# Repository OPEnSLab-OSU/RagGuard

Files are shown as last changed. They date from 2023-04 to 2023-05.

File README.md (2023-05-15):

# 🚽 RagGuard | [Wiki](https://github.com/OPEnSLab-OSU/RagGuard/wiki)
Project Lead: **Dylan Heisey**
Project Members: **Aiden Olsen**

Sewer pipes carry waste that contains fats, oils, grease (FOG), and other debris that can cause buildup and complications in the system. The RagGuard project aims to protect sensors in these pipes from FOG and debris buildup that can affect the integrity of readings. Using a motor, the RagGuard periodically shakes itself and the sensor to reduce the amount of debris affecting the sensor's performance.

More information about assembly, testing, and operation can be found at the [wiki](https://github.com/OPEnSLab-OSU/RagGuard/wiki).

# ⚙️ RagGuard Programming Instructions

## 🛠️ Arduino UNO Setup:
#### ↬ The Arduino UNO must be setup as a programmer in order to flash the ATtiny85 microcontroller that the controller board uses. In order to do this, complete the following steps:

1. In the arduino IDE do the following: `File > Examples > ArduinoISP > ArduinoISP`
2. Select the ardunio uno board and port
3. Upload the sketch

## 💾 Install ATtiny85 board core:
#### ↬ The ATtiny85 doesnt have an Arduino core by deafault so you must install it to your Arduino IDE as follows:

1. Go to `Settings`
2. Add the following url to the additional board manager URLs:
   ```
   http://drazzy.com/package_drazzy.com_index.json
   ```
3. In the `Board Manager` search for and install `ATtinyCore`

## 🔥 Burn the bootloader:
#### ↬ In order to have the correct clock speed (which is important for timing) the bootloader must be burned in the following manner:

1. Set the board: `Tools > Board > ATTinyCore > ATtiny25/45/85 (no bootloader)`
2. Set clock to `8MHz`
3. Set programmer as `Arduino as ISP`
4. Click `Tools > Burn Bootloader` to burn the bootloader

## 🚀 Upload the code:
#### ↬ Once the bootloader is burned, we can flash a sketch onto the control board using the Arduino as an In-System-Programmer (ISP).

1. Set the board: `Tools > Board > ATTinyCore > ATtiny25/45/85 (no bootloader)`
2. Set clock to `8MHz`
3. Set programmer as `Arduino as ISP`
4. Upload the `RagGuard.ino` sketch to the board w/ `Sketch > Upload Using Programmer`

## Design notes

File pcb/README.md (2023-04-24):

# Programmer PCB

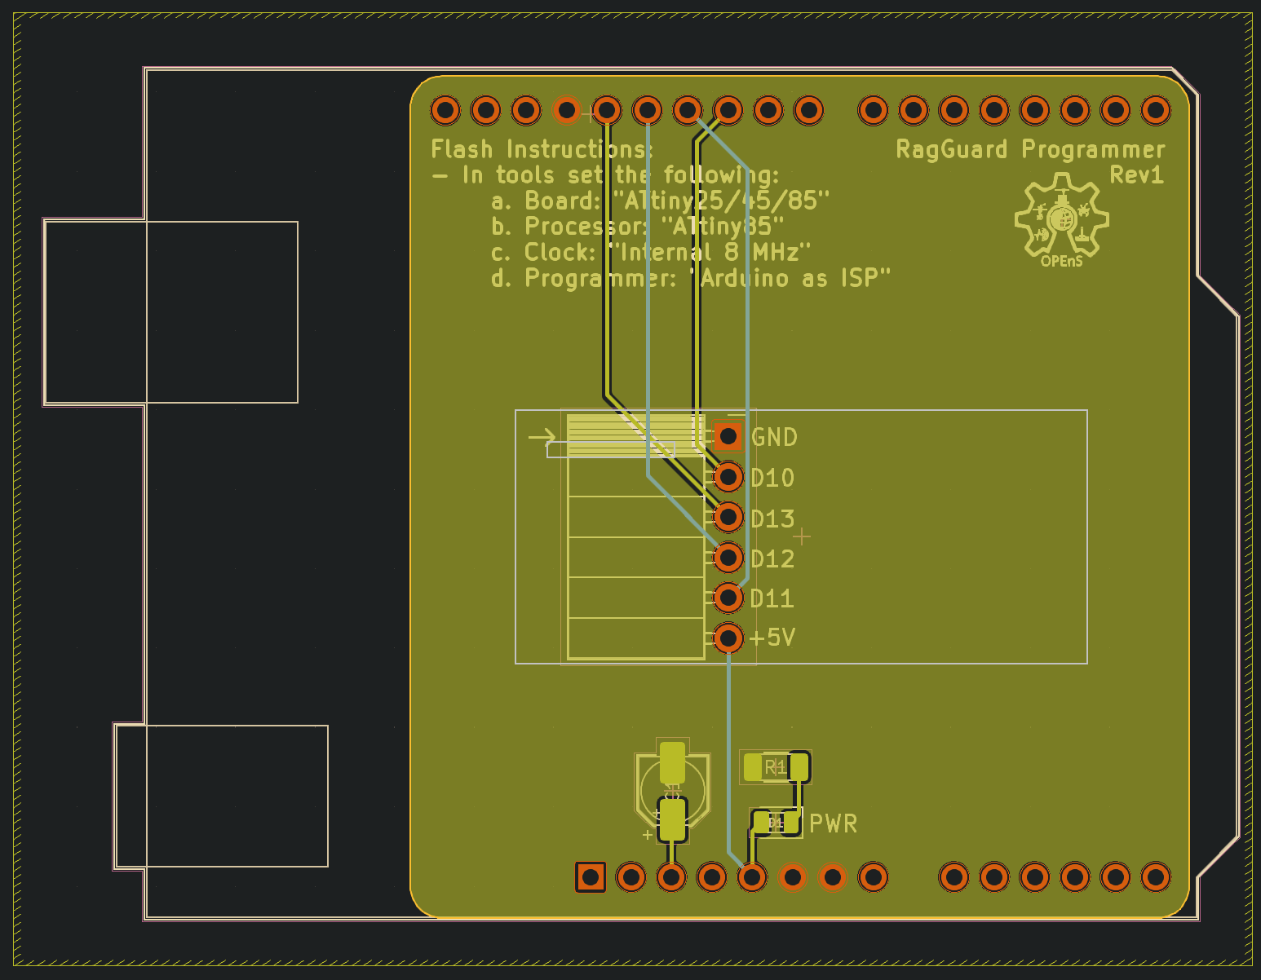
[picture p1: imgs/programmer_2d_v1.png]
programmer pcb 2d
 
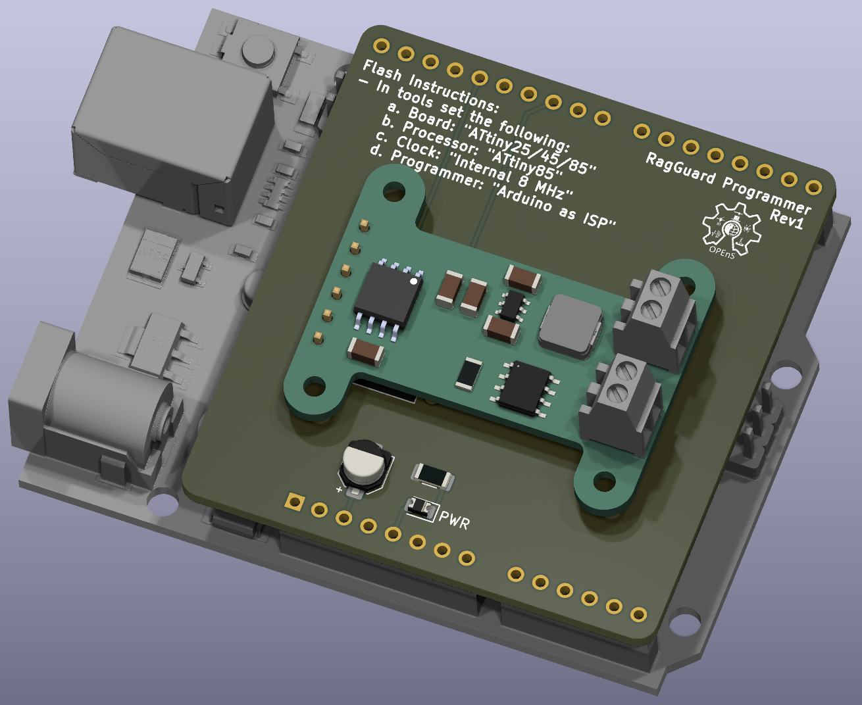
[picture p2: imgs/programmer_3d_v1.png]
programmer pcb 2d
 

# Control PCB

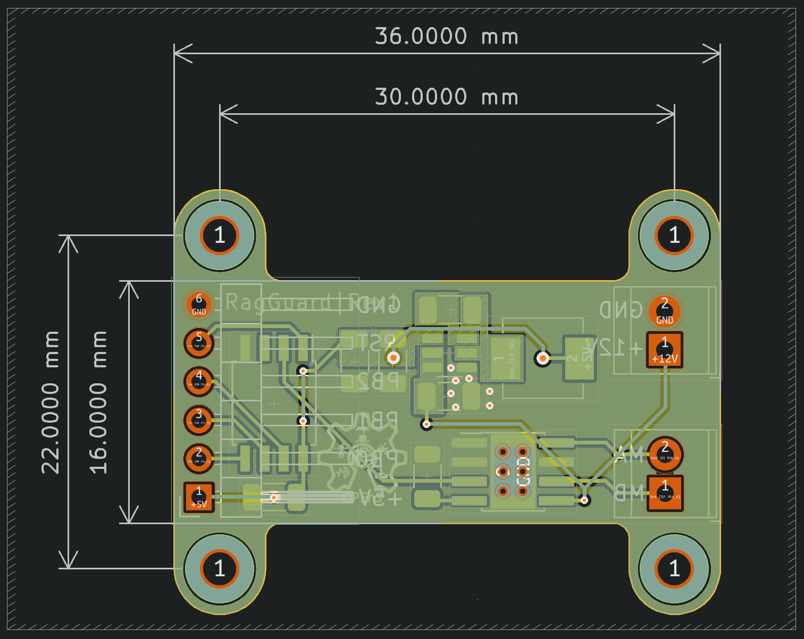
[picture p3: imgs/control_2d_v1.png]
 
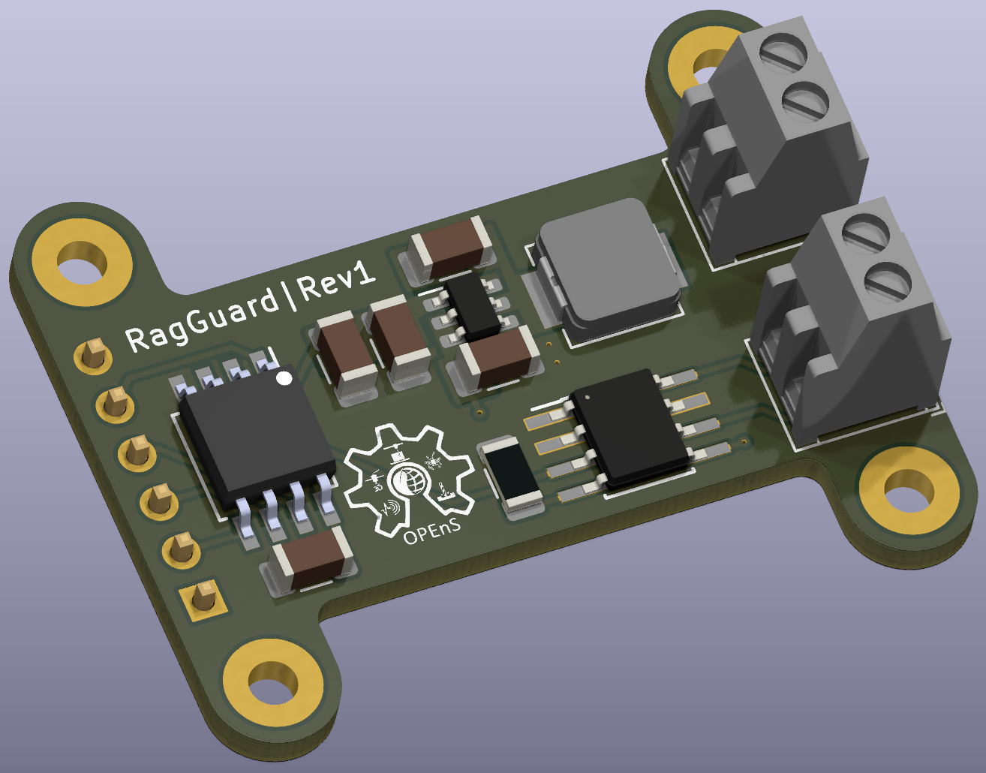
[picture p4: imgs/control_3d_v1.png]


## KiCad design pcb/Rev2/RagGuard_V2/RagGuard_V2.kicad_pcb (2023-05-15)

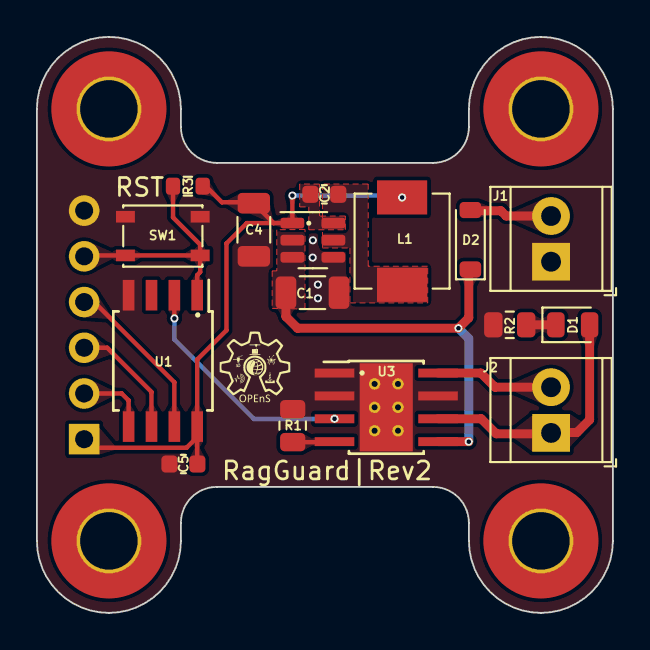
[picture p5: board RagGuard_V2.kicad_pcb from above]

Board: 2 copper layers, 32.0 x 32.0 mm, 21 parts (1 on the bottom side), 15 nets.

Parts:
C1: 10u; C_1206_3216Metric
C2, C5: 0.1u; C_0603_1608Metric
C4: 22u; C_1206_3216Metric
D1: LED; LED_0805_2012Metric
D2: D; D_SOD-123
H1, H2, H3, H4: MountingHole_Pad; MountingHole_3.2mm_M3_Pad_TopBottom
J1: BATT; TerminalBlock_TE_282834-2_1x02_P2.54mm_Horizontal
J2: MOTOR; TerminalBlock_TE_282834-2_1x02_P2.54mm_Horizontal
J4: PRGM; PinHeader_1x06_P2.54mm_Horizontal
L1: 4.7u; L_Vishay_IHLP-2020
R1: 30k; R_0805_2012Metric
R2: 2k; R_0805_2012Metric
R3: 10k; R_0603_1608Metric
SW1: RST; SW_SPST_PTS810
U1: ATtiny85-20S; SOIC-8W_5.3x5.3mm_P1.27mm
U2: AP63205WU; TSOT-23-6
U3: DRV8871DDA; Texas_HTSOP-8-1EP_3.9x4.9mm_P1.27mm_EP2.95x4.9mm_Mask2.4x3.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

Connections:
+5V: C4.1, C5.1, J4.1, L1.2, R3.1, U1.8 (VCC), U2.1 (FB)
+12V: C1.1, D2.1 (K), U2.2 (EN), U2.3 (IN), U3.5 (VM)
GND: C1.2, C4.2, C5.2, J1.1, J4.6, R1.2, R2.2, SW1.2, U1.4 (GND), U2.4 (GND), U3.1 (GND), U3.2 (IN2), U3.7 (GND), U3.9 (GND)
MOTOR_CTRL: U1.2 (XTAL1/PB3), U3.3 (IN1)
unnamed: D1.2 (A), J2.1, U3.6 (OUT1)
unnamed: D1.1 (K), R2.1
unnamed: D2.2 (A), J1.2
unnamed: J2.2, U3.8 (OUT2)
unnamed: J4.2, U1.5 (AREF/PB0)
unnamed: J4.3, U1.6 (PB1)
unnamed: J4.4, U1.7 (PB2)
unnamed: J4.5, R3.2, SW1.1, U1.1 (~RESET/PB5)
unnamed: C2.2, U2.6 (BST)
unnamed: C2.1, L1.1, U2.5 (SW)
unnamed: R1.1, U3.4 (ILIM)

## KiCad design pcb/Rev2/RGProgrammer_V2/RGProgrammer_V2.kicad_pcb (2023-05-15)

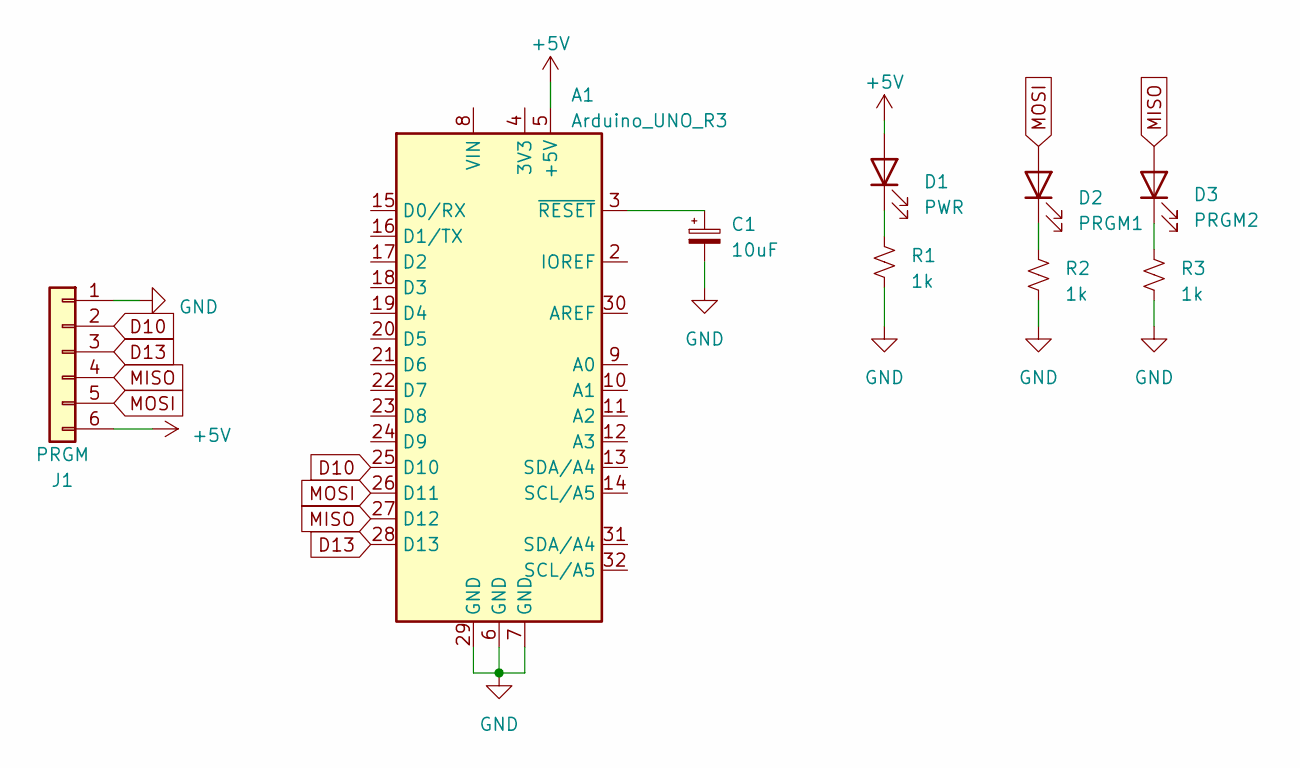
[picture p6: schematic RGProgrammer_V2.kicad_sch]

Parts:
A1: Arduino_UNO_R3
C1: 10uF; CP_Elec_4x3
D1: PWR; D_0805_2012Metric
D2: PRGM1; D_0805_2012Metric
D3: PRGM2; D_0805_2012Metric
J1: PRGM; PinSocket_1x06_P2.54mm_Horizontal
R1, R2, R3: 1k; R_0805_2012Metric

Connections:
+5V: A1.5 (+5V), D1.2 (A), J1.6
D10: A1.25 (D10), J1.2
D13: A1.28 (D13), J1.3
GND: A1.6 (GND), A1.7 (GND), A1.29 (GND), C1.2, J1.1, R1.2, R2.2, R3.2
MISO: A1.27 (D12), D3.2 (A), J1.4
MOSI: A1.26 (D11), D2.2 (A), J1.5
unnamed: A1.3 (~RESET), C1.1
unnamed: D1.1 (K), R1.1
unnamed: D2.1 (K), R2.1
unnamed: D3.1 (K), R3.1

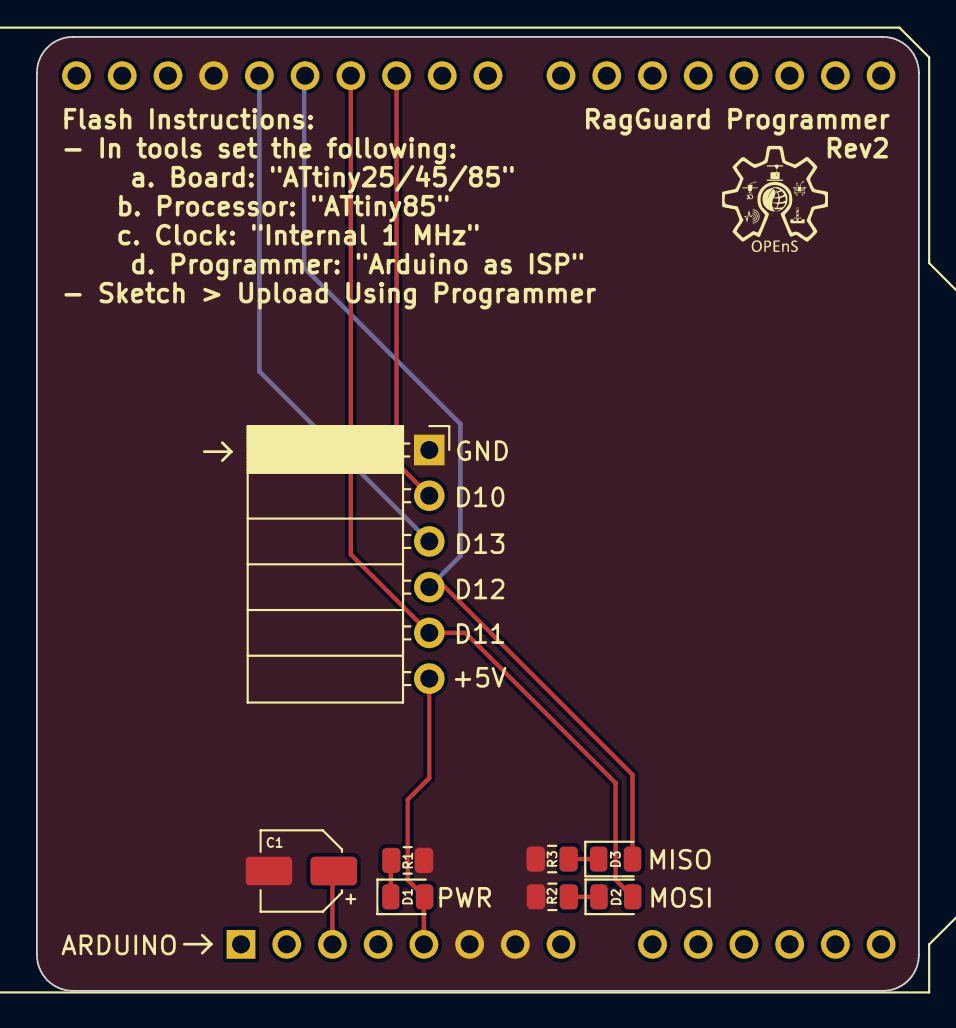
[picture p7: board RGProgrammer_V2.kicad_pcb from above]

Board: 2 copper layers, 49.0 x 53.0 mm, 9 parts (0 on the bottom side), 10 nets.

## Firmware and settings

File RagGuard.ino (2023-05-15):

/*
 * Sketch:  RagGuard.ino
 * Purpose: Turns on a motor for a set amount of time, then off
 *         for a set amount of time using an ATtiny85 uC
 * By: Aiden Olsen
 */

#define MOTOR_PIN 3
//#define MOTOR_ON_SEC 30
//#define MOTOR_OFF_MIN 60
#define MOTOR_ON_SEC 1
#define MOTOR_OFF_SEC 1

const long delay_on_ms = MOTOR_ON_SEC * 1000;
//const long delay_off_ms = MOTOR_OFF_MIN * 60 * 1000;
const long delay_off_ms = MOTOR_OFF_SEC * 1000;

void setup() {
  // initialize motor pin low
  pinMode(MOTOR_PIN, OUTPUT);
  digitalWrite(MOTOR_PIN, LOW);
}

void loop() {
  // start motor for MOTOR_ON_SEC
  digitalWrite(MOTOR_PIN, HIGH);
  delay(delay_on_ms);
  // stop motor for MOTOR_OFF_MIN
  digitalWrite(MOTOR_PIN, LOW);
  delay(delay_off_ms);
}

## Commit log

2023-04-24 added V1 gerber files for both programmer and control board
    [RGProgrammer_V1-B_Cu.gbr, RGProgrammer_V1-B_Mask.gbr, RGProgrammer_V1-B_Paste.gbr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]
2023-04-24 Added pcb readme and images
2023-04-24 added kicad files for v1 control board
    [RagGuard_V1.kicad_pcb, RagGuard_V1.kicad_sch]
2023-05-15 organized Rev1 pcb
    [RGProgrammer_V1-B_Cu.gbr, RGProgrammer_V1-B_Mask.gbr, RGProgrammer_V1-B_Paste.gbr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]
2023-05-15 added second revision PCBss
    [RGProgrammer_V2-B_Cu.gbr, RGProgrammer_V2-B_Mask.gbr, RGProgrammer_V2-B_Paste.gbr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]
